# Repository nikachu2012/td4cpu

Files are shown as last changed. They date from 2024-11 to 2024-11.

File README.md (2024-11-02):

# TD4 CPU
書籍「CPUの創りかた」にあるTD4 CPUの回路を、ユニバーサル基板で作るのがめんどくさかったので基板にしたものです。
製作の際は書籍を購入することをお勧めします。

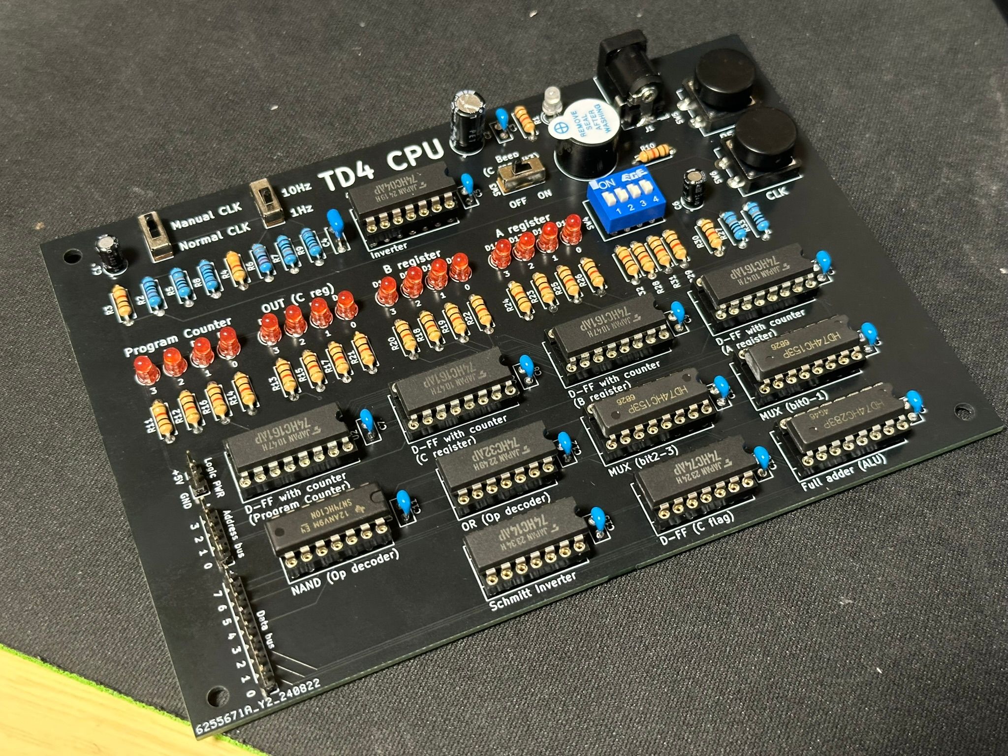
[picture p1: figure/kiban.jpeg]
kiban

*完成させた基板のサンプル*

## フォルダ解説
### `schematic`
回路図と基板のKiCadデータが入っています。バージョンは8.0です。
なんかのフットプリントをライブラリで入れてた気がしますがなくても読めるっぽいです。

### `schematic_pdf`
回路図のpdfファイルが入っています。

### `rom_emulator`
ArduinoなどのマイコンでROMを作るためのプログラムが入っています。  
Arduino UNO系と、Raspberry Pi Pico(MicroPython)があります。

#### Arduino UNO系
Arduino UNO R4 WiFiで動作確認しています。  
ポートレジスタの操作ではなく`digitalWrite`を使っているのでMinimaやR3でも動くと思います。

以下のように接続してください。

| Arduino側 | TD4 CPU側 |
| --- | --- |
| VIN | +5V |
| GND | GND |
| D11 | Address bus 3 |
| D10 | Address bus 2 |
| D9 | Address bus 1 |
| D8 | Address bus 0 |
| D7 | Data bus 7 |
| D6 | Data bus 6 |
| D5 | Data bus 5 |
| D4 | Data bus 4 |
| D3 | Data bus 3 |
| D2 | Data bus 2 |
| D1 | Data bus 1 |
| D0 | Data bus 0 |

#### Raspberry Pi Pico
Raspberry Pi Pico無印で動作確認済みです。
ファイル名を`main.py`に変更して送信すれば動作すると思います。

以下のように接続してください。

| Raspberry Pi Pico側 | TD4 CPU側 |
| --- | --- |
| 39 VSYS | +5V |
| 38 GND | GND |
| 4  GP2 | Address bus 3 |
| 5  GP3 | Address bus 2 |
| 6  GP4 | Address bus 1 |
| 7  GP5 | Address bus 0 |
| 9  GP6 | Data bus 7 |
| 10 GP7 | Data bus 6 |
| 11 GP8 | Data bus 5 |
| 12 GP9 | Data bus 4 |
| 13 GP10 | Data bus 3 |
| 14 GP11 | Data bus 2 |
| 15 GP12 | Data bus 1 |
| 16 GP13 | Data bus 0 |

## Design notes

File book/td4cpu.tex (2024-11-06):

\documentclass[xelatex,a5paper,ja=standard, openany]{bxjsbook}

\input{preamble.tex}

\title{}
\author{} 
\date{}

\begin{document}
\tableofcontents

\chapter{CPUの概要}

CPUの基板をご購入いただきありがとうございます。と説明書っぽいことを言ってみる。まあ書くこともないし、紙が無駄なのでこれぐらいにする。

\section{基板}

\begin{figure}[h]
    \centering
    
    \caption{完成した基板}
    \label{fig:kanseikiban}
\end{figure}

このCPUは、書籍「CPUの創りかた\footnote{\texttt{\url{https://book.mynavi.jp/ec/products/detail/id=22065} (ISBN4-8399-0986-5)}}」で製作するTD4 CPUの回路を、筆者が基板に起こしたものになる。\par
書籍ではユニバーサル基板上に配線していたが、そんなことしたくなかったので基板を作ることにした。基板設計など一切したことなかったので、専門家が見たら怒る点もあると思うが、気にしないでほしい。
部品を実装すれば動くと思うが、書籍も参照しながら作ることをおすすめする。\par

基板の設計はKiCad 8.0を利用した。無料のCADだが非常に使いやすかった。また、基板はJLCPCBに発注した。
\section{CPU}
CPUの概要を以下に示す。

\begin{itemize}
    \item 命令データ長 8bit
    \item アドレスバス長 4bit
    \item 2つの4bitレジスタ(A,B)
    \item 4bit 入出力 (IN, OUT)
    \item 4bit プログラムカウンタ
    \item ALUは全加算器のみ
\end{itemize}

命令フォーマットは、図\ref{fig:op_format}のように、上位4bitが命令コード、下位4bitがイミディエイトデータの計8bit構成となっている。
\begin{figure}[h]
    \centering
    
    \caption{命令フォーマット}
    \label{fig:op_format}
\end{figure}

\newpage
命令コードの一覧と意味、ニーモニックを表\ref{table:opcode_list}に示す。

\begin{table}[h]
    \centering
    \begin{tabular}{lll}
        ニーモニック                   & 命令コード                  & 意味                                       \\
        \hline
        \texttt{MOV A, {[}Im{]}} & \texttt{0011 {[}Im{]}} & A\textleftarrow Im                       \\
        \texttt{MOV B, {[}Im{]}} & \texttt{0111 {[}Im{]}} & B\textleftarrow Im                       \\
        \texttt{MOV A, B}        & \texttt{0001 0000}     & A\textleftarrow B                        \\
        \texttt{MOV B, A}        & \texttt{0100 0000}     & B\textleftarrow A                        \\
        \texttt{ADD A, {[}Im{]}} & \texttt{0000 {[}Im{]}} & A\textleftarrow A + Im                   \\
        \texttt{ADD B, {[}Im{]}} & \texttt{0101 {[}Im{]}} & B\textleftarrow B + Im                   \\
        \texttt{IN A}            & \texttt{0010 0000}     & A\textleftarrow IN                       \\
        \texttt{IN B}            & \texttt{0110 0000}     & B\textleftarrow IN                       \\
        \texttt{OUT {[}Im{]}}    & \texttt{1011 {[}Im{]}} & OUT\textleftarrow Im                     \\
        \texttt{OUT B}           & \texttt{1001 {[}Im{]}} & OUT\textleftarrow Im                     \\
        \texttt{JMP {[}Im{]}}    & \texttt{1111 {[}Im{]}} & PC\textleftarrow Im                      \\
        \texttt{JNC {[}Im{]} }   & \texttt{1110 {[}Im{]}} & if (C is not 1) then PC\textleftarrow Im
    \end{tabular}
    \caption{命令コードの一覧}
    \label{table:opcode_list}
\end{table}

\chapter{製作}
CPUの概要や回路を説明するのは書籍に任せるとして、この基板の製作について述べる。

\section{部品表}
基板以外に別途、別紙１に示した部品が必要となる。部品は必要個数のみ表記しているので、予備も含めて買うのをお勧めする。\par

部品については秋月電子通商\footnote{\url{https://akizukidenshi.com/catalog/default.aspx}}と樫木総業株式会社\footnote{\url{https://www.kashinoki.shop/}}ですべて購入できる。秋月電子通商で買える部品については秋葉原店の店頭ですべて購入できた(2024年8月現在)。\texttt{74HC14}だけバックヤードにあるためレジで店員に言わなければならないので注意。\par

秋葉原には秋月以外にもマルツや千石通商など、電子部品の店が多くある。この機会に秋葉原に出向いて色々なお店を見ながら選ぶと楽しいと思う。

\section{部品の実装}
はんだごて片手にひたすらはんだ付けする。表面実装部品は無いのではんだ付けの難易度は低いと思う。ただ量が多い。\par
暇だったのでアニメを見ながらはんだ付けをしていた。\par
このCPUの製作ではんだ付けを初めて行うという人は、はんだ付けの動画などを見て学ぶことをお勧めする。くれぐれも火傷には気を付けてほしい。

\subsection{注意点}
部品実装の注意点としては、電解コンデンサ(MLCCと書いていないもの)は極性\footnote{簡単に言えば部品のプラスマイナスの向きのこと。逆につなぐと爆発などの危険がある}がある。

\begin{figure}[ht]
    \centering
    \begin{minipage}[t]{0.45\linewidth}
        \centering
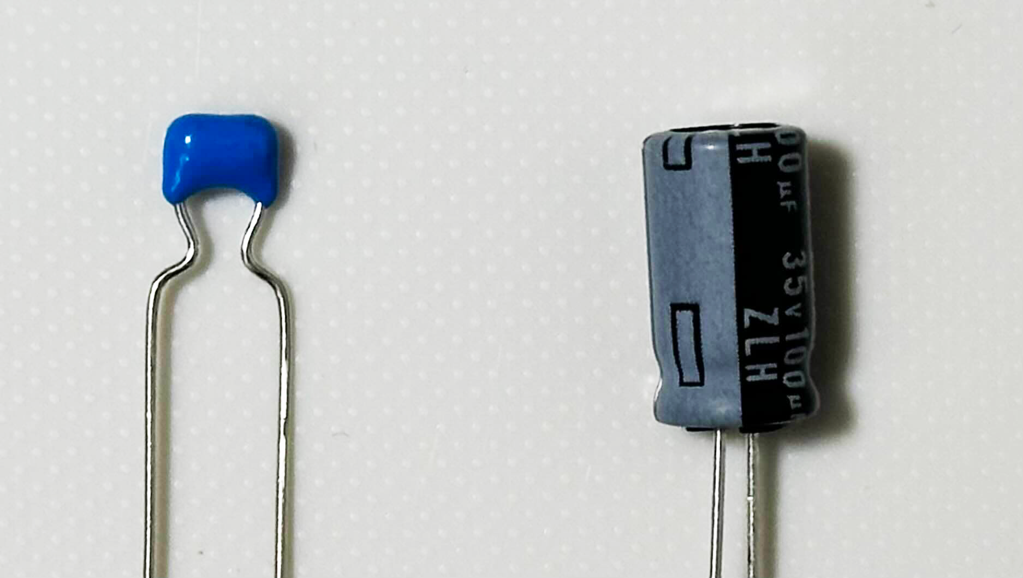
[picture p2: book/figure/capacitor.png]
        
        \caption{積層セラミックコンデンサ(左)と電解コンデンサ(右)}
        \label{fig:capacitor}
    \end{minipage}
    \begin{minipage}[t]{0.45\linewidth}
        \centering
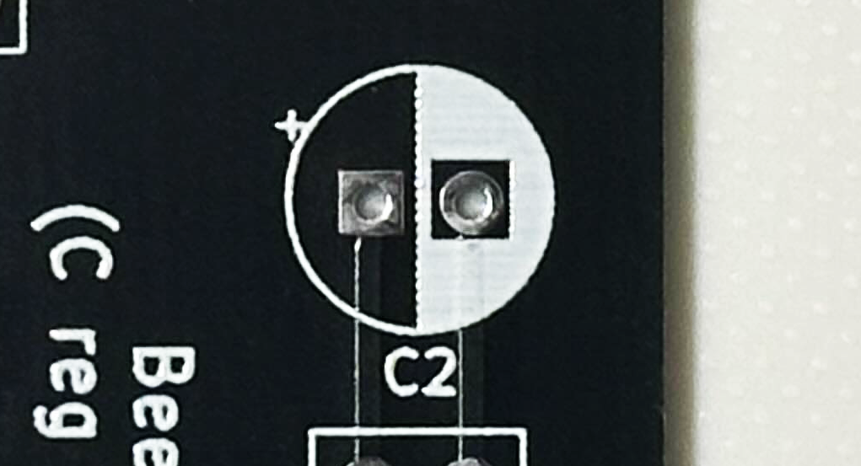
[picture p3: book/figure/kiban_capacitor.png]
        
        \caption{基板上の電解コンデンサの表記}
        \label{fig:capacitor_kiban}
    \end{minipage}
\end{figure}

電解コンデンサを見ると半分が白くなっていて、でかでかと-（マイナス）が書かれていると思う。これと基板上の白い部分の向きを合わせれば問題ない。また、積層セラミックコンデンサについては極性はない。\par

\hrulefill

\begin{figure}[h]
    \centering
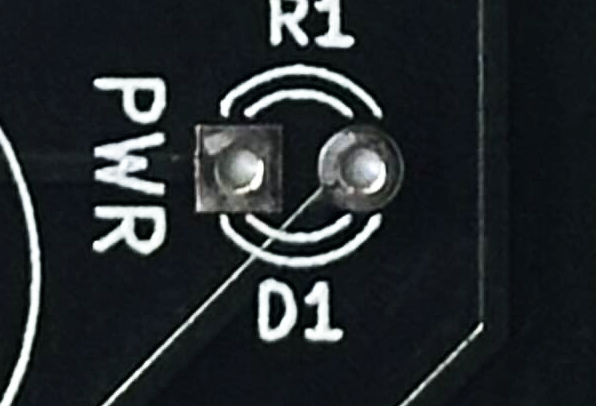
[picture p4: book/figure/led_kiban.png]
    
    \caption{基板上のLEDの表記}
    \label{fig:led_kiban}
\end{figure}

電源やレジスタの値の表示用にLED(発光ダイオード)を利用している。これも極性があるので注意してほしい。部品を刺す穴の周りの金属が四角いほう(図\ref{fig:led_kiban}では左側)がマイナス(LEDの足が短い方)になる。最悪こちらは逆につないでも光らないだけで回路に影響は無いはず。

ICは印刷されている切り欠きとICの切り欠きを合わせて差し込むようにする。逆だと正しく動かなかったり、ICを壊す可能性もある。というか絶対に壊す。ICソケットを使用する場合はICソケットにも切り欠きがあるので合わせるのが良い。

\begin{figure}[ht]
    \centering
    \begin{minipage}[t]{0.4\linewidth}
        \centering
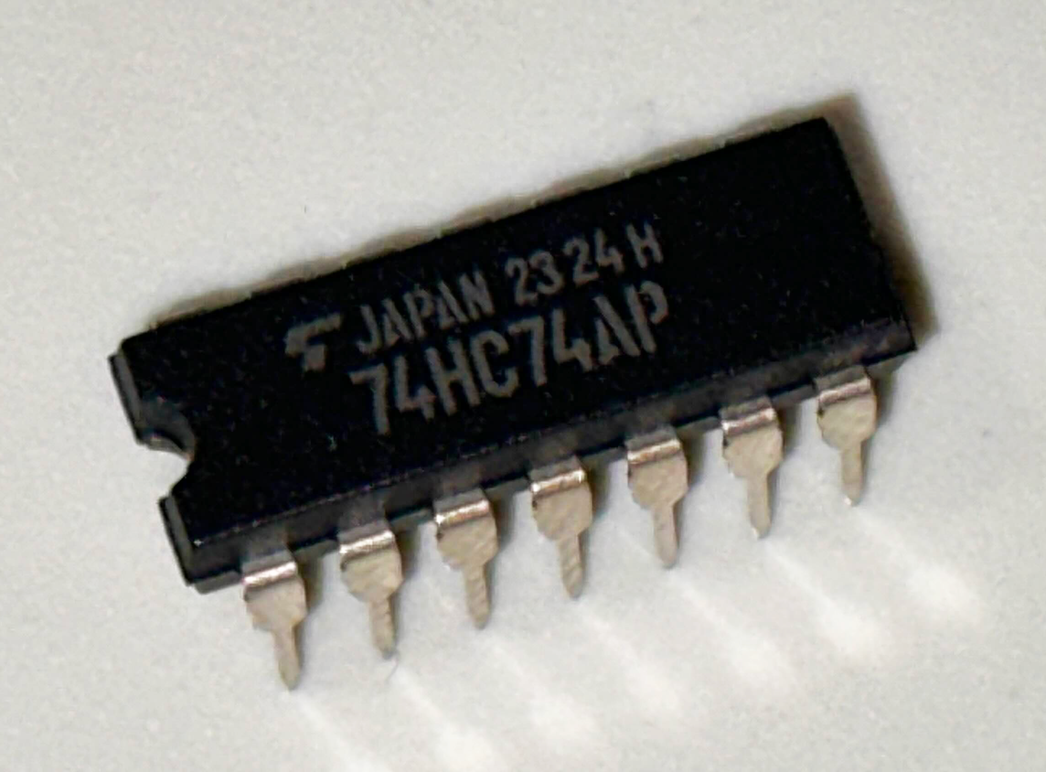
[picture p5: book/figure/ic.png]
        
        \caption{ICの外観}
        \label{fig:ic_overview}
    \end{minipage}
    \begin{minipage}[t]{0.45\linewidth}
        \centering
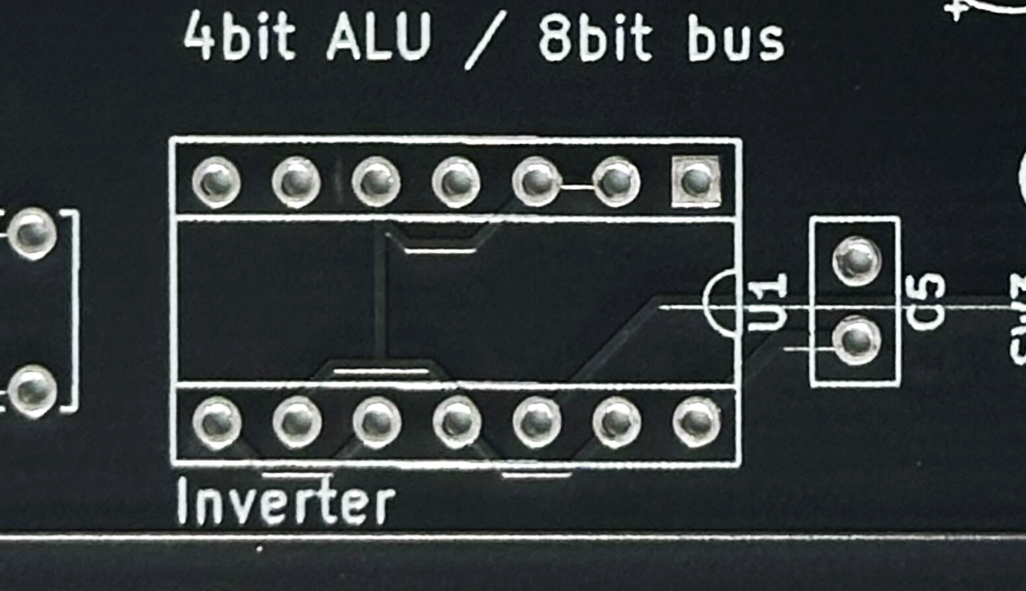
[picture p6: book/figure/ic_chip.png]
        
        \caption{基板上のICの印刷}
        \label{fig:ic_print}
    \end{minipage}
\end{figure}

\chapter{動作確認と使用}
はんだ付けが終わって完成してもTD4 CPUにはROMがないため、正しく動かない。そのためにまずはROMを用意する必要がある。

\section{ROM}
書籍ではROMは16個8PDIPスイッチを並べて製作していた。この方法はビジュアルとしては良いが結構部品代がかかるので断念した。
アドレスバスとデータバスを引き出しているので、ここに適当なROMを接続すれば良いが、筆者はArduinoでROMを作ることにした。

\begin{figure}[h]
    \centering
    
    \caption{Arduinoで作ったROMで動くTD4 CPU}
    \label{fig:td4withROM}
\end{figure}

\newpage

プログラムは以下の通り。

\lstinputlisting[language=c++]{td4_rom_arduino_new.ino}

Arduino UNO R4 WiFiで動作確認しているが、他でも動くと思う。あとはArduino側のD0-D7ピンをデータバスの0-7に、D8-D11をアドレスバスの0-3にそれぞれ接続し、+5VとVinを接続し、GND同士を接続してどちらかに電源を入れればプログラムが実行される。\par

\newpage

またPWRピンがあるがこれは入出力どちらでも使えるので、Arduino側から供給しても\footnote{Arduino側から供給する場合、電流制限に注意}、CPU側から供給しても良い。

\section{アセンブラー}
書籍ではアセンブル\footnote{人間に読みやすいように書かれたニーモニックを機械語に変換する処理}はハンドアセンブルのみが書かれていたが、めんどくさかったのでアセンブラーを作った。Linux上で動かすことを想定しているので、Windowsを使っている場合WSL上で行うことをお勧めする。

ビルドには\texttt{gcc, make, git, flex, bison}が必要なのでインストールする。Ubuntuを利用している場合は以下の通りになる。
\begin{lstlisting}
$ sudo apt update
$ sudo apt upgrade
$ sudo apt install gcc make git flex bison libbison-dev
\end{lstlisting}

ビルドは以下のコマンドで行う。
\begin{lstlisting}
$ cd ~
$ git clone https://github.com/nikachu2012/td4asm
$ cd td4asm
$ make all
\end{lstlisting}

test.asmというファイルををtd4asmと同じ場所に作り、中身を以下のようにする。
\begin{lstlisting}[caption=LEDちかちかさせるプログラム \texttt{test.asm}]
main: out 0b0011
      out 0b0110
      out 0b1100
      out 0b1000
      out 0b1000
      out 0b1100
      out 0b0110
      out 0b0011
      out 0b0001
      jmp main
\end{lstlisting}

以下のコマンドを実行するとtest.txtが作られる。
\begin{lstlisting}
$ ./td4asm -i test.asm -o test.txt -c
\end{lstlisting}

test.txtは以下のようになる。
\begin{lstlisting}
{0xb3, 0xb6, 0xbc, 0xb8, 0xb8, 0xbc, 0xb6, 0xb3, 0xb1, 0xf0, 0x00, 0x00, 0x00, 0x00, 0x00, 0x00}
\end{lstlisting}

このように、C言語の配列形式で機械語が出力される。

\chapter{最後に}

この本のPDFファイル、回路図などは以下のURLに用意した。

\centerline{\url{https://github.com/nikachu2012/td4cpu}}

また、すべての質問に答えられるかわからないが、このCPUの基板やアセンブラーについてわからない点などがあれば、奥付に記載のメールアドレスまで連絡していただければできるだけ質問に答える。

\vspace*{\fill}

\begin{tabular*}{\textwidth}{l}
    \noindent
    \textbf{\sffamily\Large 4bit CPU 製作基板\;説明書\normalsize}\vspace{3mm} \\
    \hline
    \begin{tabular}{@{}rrrl}
        2024年 & 11月 & 1日 & 初版第1刷発行\;\;(沼津高専\;第59回高専祭) \\
        % 2029年 & 1月 & 1日 & 初版第2刷発行\;\;(沼津高専\;第60回高専祭)
    \end{tabular} \\
    \\
    \begin{tabular}{@{}ll}
        \textbf{著者}  & \texttt{@nikachu2012} (荻野\;壮)                          \\
        \textbf{発行者} & \begin{tabular}{@{}l@{}}
                           \texttt{@nikachu2012} (荻野\;壮)  \\
                           \texttt{work@nikachu.net}
                       \end{tabular}               \\
        \textbf{発行所} & 沼津高専\;情報工学同好会(非公認)                          \\
        \textbf{印刷者} & 自分                                 \\
    \end{tabular} \\
    \hline
    Printed in Japan(多分)
\end{tabular*}

\end{document}

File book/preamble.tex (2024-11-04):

% 各種パッケージ
\usepackage{graphicx} % figure環境
\usepackage{titlesec}
\usepackage{hyperref}

\usepackage{noto}
\usepackage[T1]{fontenc} % 欧文フォント変えるときのおまじない

\usepackage{listings}
\renewcommand{\lstlistingname}{ソースコード}

\lstset{
    basicstyle={\ttfamily\gtfamily\scriptsize},
    identifierstyle={},
    commentstyle={},
    keywordstyle={\bfseries},
    ndkeywordstyle={},
    stringstyle={\ttfamily},
    frame={tb},
    breaklines=true,
    columns=[l]{fullflexible},
    numbers=left,
    numberstyle={\ttfamily\tiny},
    stepnumber=1,
    tabsize=4,
    keywordstyle={},     %キーワード(int, ifなど)の書体指定
    commentstyle={},  %注釈の書体
    stringstyle={},        %文字列
    showstringspaces=false,  %文字列中の半角スペースを表示させない
    keepspaces=true,
}

\pagestyle{headings}

% chapter
\titleformat{\chapter}[block]
{\bfseries\gtfamily\sffamily\Huge}
{\Large 第\thechapter 章\\\Huge}{0pt}
{}
[\titlerule]

\titlespacing*{\chapter}{0pt}{0em}{1.5em}[0pt] % 余白指定

% section
\titleformat{\section}[block]
{\bfseries\gtfamily\sffamily\Large}
{\thesection}{10pt}
{}
[\titlerule]

% subsection
\titleformat{\subsection}[block]
{\bfseries\gtfamily\sffamily\large}
{\thesubsection}{10pt}
{}
[\titlerule]

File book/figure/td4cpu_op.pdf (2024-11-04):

0 | 0 | 1 | 1 | 1 | 1 | 1 | 1
MSB | 7 | 6 | 5 | 4 | 3 | 2 | 1 | 0 | LSB
命令コード | イミディエイトデータ

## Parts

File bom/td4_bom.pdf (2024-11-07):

別紙１ 部品表 | 価格は2024年11月時点の価格
リファレンス番号 | 部品種類 | 販売ページ | メモ | 必要個数 参考単価 価格
BZ1 | Beep Buzzer | https://akizukidenshi.com/catalog/g/g109800/ | 12mmの電子ブザー
| | | (圧電スピーカーではなく、発振回路を内蔵しているやつ） | 1 | 70 | 70
C1,C6 | 10μF 16V | https://akizukidenshi.com/catalog/g/g110590/ | | 2 | 10 | 20
C2 | 100μF 16V | https://akizukidenshi.com/catalog/g/g102724/ | 大元の一番でかいコンデンサ | 1 | 15 | 15
C3,C5,C7-C17 | 0.1μF MLCC | https://akizukidenshi.com/catalog/g/g113582/ | 10個入り | 13 | 100 | 100
C4 | 10μF 16V MLCC | https://akizukidenshi.com/catalog/g/g102184/ | 10個入り | 1 | 200 | 200
D1-D17 | LED | https://akizukidenshi.com/catalog/g/g111577/ | 3mmのやつ
| | | 筆者は秋葉原マルツの処分セールでめっちゃ安いやつにした | 17 | | 100
J1 | Jack-DC | https://akizukidenshi.com/catalog/g/g109408/ | 内径2.1 外径5.5のやつ | 1 | 30 | 1
J2,J3,J4 | Logic, Address, Data | https://akizukidenshi.com/catalog/g/g100167/ | ピンヘッダ全部で14ピン分 | 3 | 35 | 35
R1,R3,R10-R26,R28-R32 | 1k | https://akizukidenshi.com/catalog/g/g125102/ | 100個入り 普通の抵抗 | 24 | 100 | 100
R2 | 10k | https://akizukidenshi.com/catalog/g/g125103/ | 100個入り 普通の抵抗 | 1 | 100 | 100
R4 | 3.3k | https://akizukidenshi.com/catalog/g/g125332/ | 100個入り 普通の抵抗 | 1 | 140 | 140
R5,R7,R27,R33 | 100k | https://akizukidenshi.com/catalog/g/g125104/ | 100個入り 普通の抵抗 | 4 | 130 | 130
R6 | 33k | https://akizukidenshi.com/catalog/g/g125333/ | 100個入り 普通の抵抗 | 1 | 150 | 150
R8,R9 | 100 | https://akizukidenshi.com/catalog/g/g125101/ | 100個入り 普通の抵抗 | 2 | 140 | 140
SW1,SW2,SW3 | SW_SPDT | https://akizukidenshi.com/catalog/g/g115707/ | 1回路2接点スライドスイッチ
| | | (クロック種別、周波数、ビープ音切り替え） | 3 | 20 | 60
SW4 | DIP | https://akizukidenshi.com/catalog/g/g100586/ | 4P DIPスイッチ (Cレジスタ入力用) | 1 | 80 | 80
SW5, SW6 | RESET, Manual CLK | https://akizukidenshi.com/catalog/g/g109826/ | 12mm角のタクトスイッチ (リセット、マニュアルクロック用) | 2 | 30 | 60
U1 | 74HC04 | https://akizukidenshi.com/catalog/g/g114058/ | インバータ DIP14P (ビープ音の電流を稼ぐため) | 1 | 30 | 30
U2,U3,U4,U5 | 74HC161 | https://www.kashinoki.shop/?pid=122479142 | 4bitカウンタ/レジスタ DIP16P
| | | (レジスタ、プログラムカウンタ) | 4 | 99 | 396
U6 | 74HC10 | https://www.kashinoki.shop/?pid=122479082 | 3入力3回路NAND DIP14P | 1 | 55 | 55
U7 | 74HC14 | https://akizukidenshi.com/catalog/g/g110923/ | シュミットトリガインバータ DIP14P | 1 | 40 | 40
U8 | 74HC32 | https://www.kashinoki.shop/?pid=122479093 | 4回路OR DIP14P | 1 | 28 | 28
U9 | 74HC74 | https://akizukidenshi.com/catalog/g/g110879/ | 2回路Dフリップフロップ DIP14P (Carry Flag) | 1 | 25 | 25
U10,U12 | 74HC153 | https://www.kashinoki.shop/?pid=122479134 | 4chマルチプレクサ DIP16P | 2 | 59 | 118
U11 | 74HC283 | https://www.kashinoki.shop/?pid=122479187 | 4bit全加算器 DIP16P (ALU) | 1 | 187 | 187
| | https://akizukidenshi.com/catalog/g/g100029/ | ICソケット 16P | 7 | 40 | 280
| | https://akizukidenshi.com/catalog/g/g100028/ | ICソケット 14P | 5 | 30 | 150
| | https://akizukidenshi.com/catalog/g/g111996/ | スイッチングACアダプタ 5V2A
| | | (内径2.1 外径5.5 センタープラス) | 1 | 770 | 770
@nikachu2012 | この部品表は以下のURLにもあります。 https://github.com/nikachu2012/td4cpu/blob/main/bom/td4_bom.csv

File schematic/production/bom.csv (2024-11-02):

Designator | Footprint | Quantity | Value | LCSC Part #
BZ1 | Buzzer_12x9.5RM7.6 | 1 | Beep Buzzer
C1, C6 | CP_Radial_D4.0mm_P1.50mm | 2 | 10μF 16V
C10, C11, C12, C13, C14, C15, C16, C17, C3, C5, C7, C8, C9 | C_Disc_D5.0mm_W2.5mm_P2.50mm | 13 | 0.1μF
C2 | CP_Radial_D6.3mm_P2.50mm | 1 | 100μF 16V
C4 | C_Disc_D6.0mm_W2.5mm_P5.00mm | 1 | 10μF 16V MLCC
D1, D10, D11, D12, D13, D14, D15, D16, D17, D2, D3, D4, D5, D6, D7, D8, D9 | LED_D3.0mm | 17 | LED
J1 | BarrelJack_GCT_DCJ200-10-A_Horizontal | 1 | Jack-DC
J2 | PinHeader_1x02_P2.54mm_Vertical | 1 | Power
J3 | PinHeader_1x04_P2.54mm_Vertical | 1 | ADDRESS
J4 | PinHeader_1x08_P2.54mm_Vertical | 1 | DATA
R1, R10, R11, R12, R13, R14, R15, R16, R17, R18, R19, R20, R21, R22, R23, R24, R25, R26, R28, R29, R3, R30, R31, R32 | R_Axial_DIN0207_L6.3mm_D2.5mm_P7.62mm_Horizontal | 24 | 1k
R2 | R_Axial_DIN0207_L6.3mm_D2.5mm_P7.62mm_Horizontal | 1 | 10k
R27, R33, R5, R7 | R_Axial_DIN0207_L6.3mm_D2.5mm_P7.62mm_Horizontal | 4 | 100k
R4 | R_Axial_DIN0207_L6.3mm_D2.5mm_P7.62mm_Horizontal | 1 | 3.3k
R6 | R_Axial_DIN0207_L6.3mm_D2.5mm_P7.62mm_Horizontal | 1 | 33k
R8, R9 | R_Axial_DIN0207_L6.3mm_D2.5mm_P7.62mm_Horizontal | 2 | 100
SW1, SW2 | SS12D00G3 | 2 | SW_SPDT
SW3 | SS12D00G3 | 1 | Beep Toggle
SW4 | SW_DIP_SPSTx04_Slide_9.78x12.34mm_W7.62mm_P2.54mm | 1 | DIP
SW5 | SW_PUSH-12mm_Wuerth-430476085716 | 1 | Reset SW
SW6 | SW_PUSH-12mm_Wuerth-430476085716 | 1 | Manual CLK
U1 | DIP-14_W7.62mm_Socket | 1 | 74HC04
U10, U12 | DIP-16_W7.62mm_Socket | 2 | 74HC153
U11 | DIP-16_W7.62mm_Socket | 1 | 74HC283
U2, U3, U4, U5 | DIP-16_W7.62mm_Socket | 4 | 74HC161
U6 | DIP-14_W7.62mm_Socket | 1 | 74HC10
U7 | DIP-14_W7.62mm_Socket | 1 | 74HC14
U8 | DIP-14_W7.62mm_Socket | 1 | 74HC32
U9 | DIP-14_W7.62mm_Socket | 1 | 74HC74

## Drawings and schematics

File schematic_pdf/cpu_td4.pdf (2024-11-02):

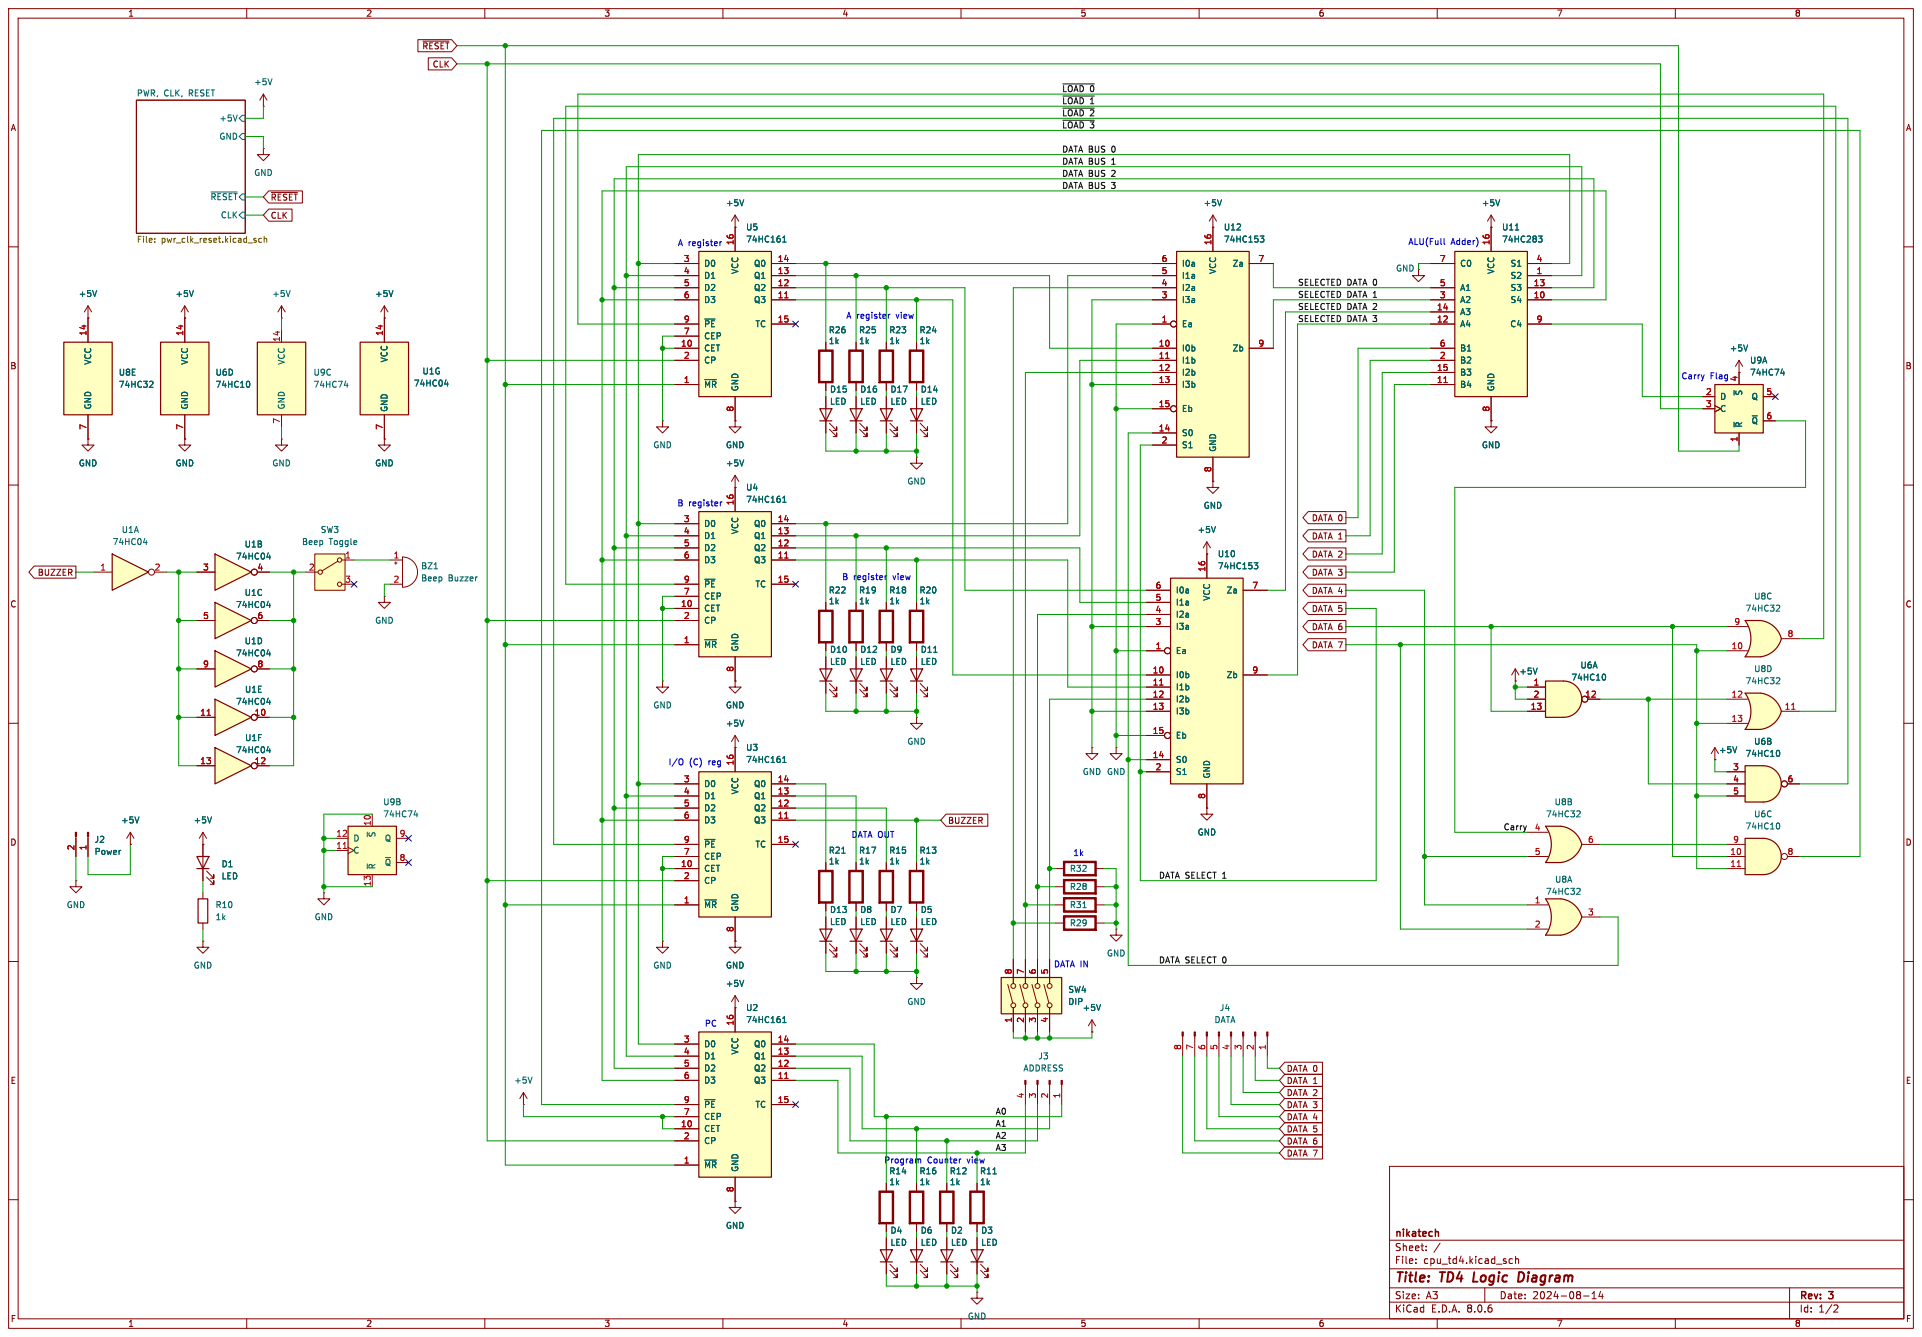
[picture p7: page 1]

~{RESET} PWR, CLK, RESET

ALU(Full Adder) DATA OUT B register
1k A register

DATA 5 DATA 0 DATA 3 DATA 7 DATA 2 DATA 6

DATA 3 DATA 5 DATA 0 DATA 4 DATA 1 BUZZER

Id: 1/2 Title: TD4 Logic Diagram

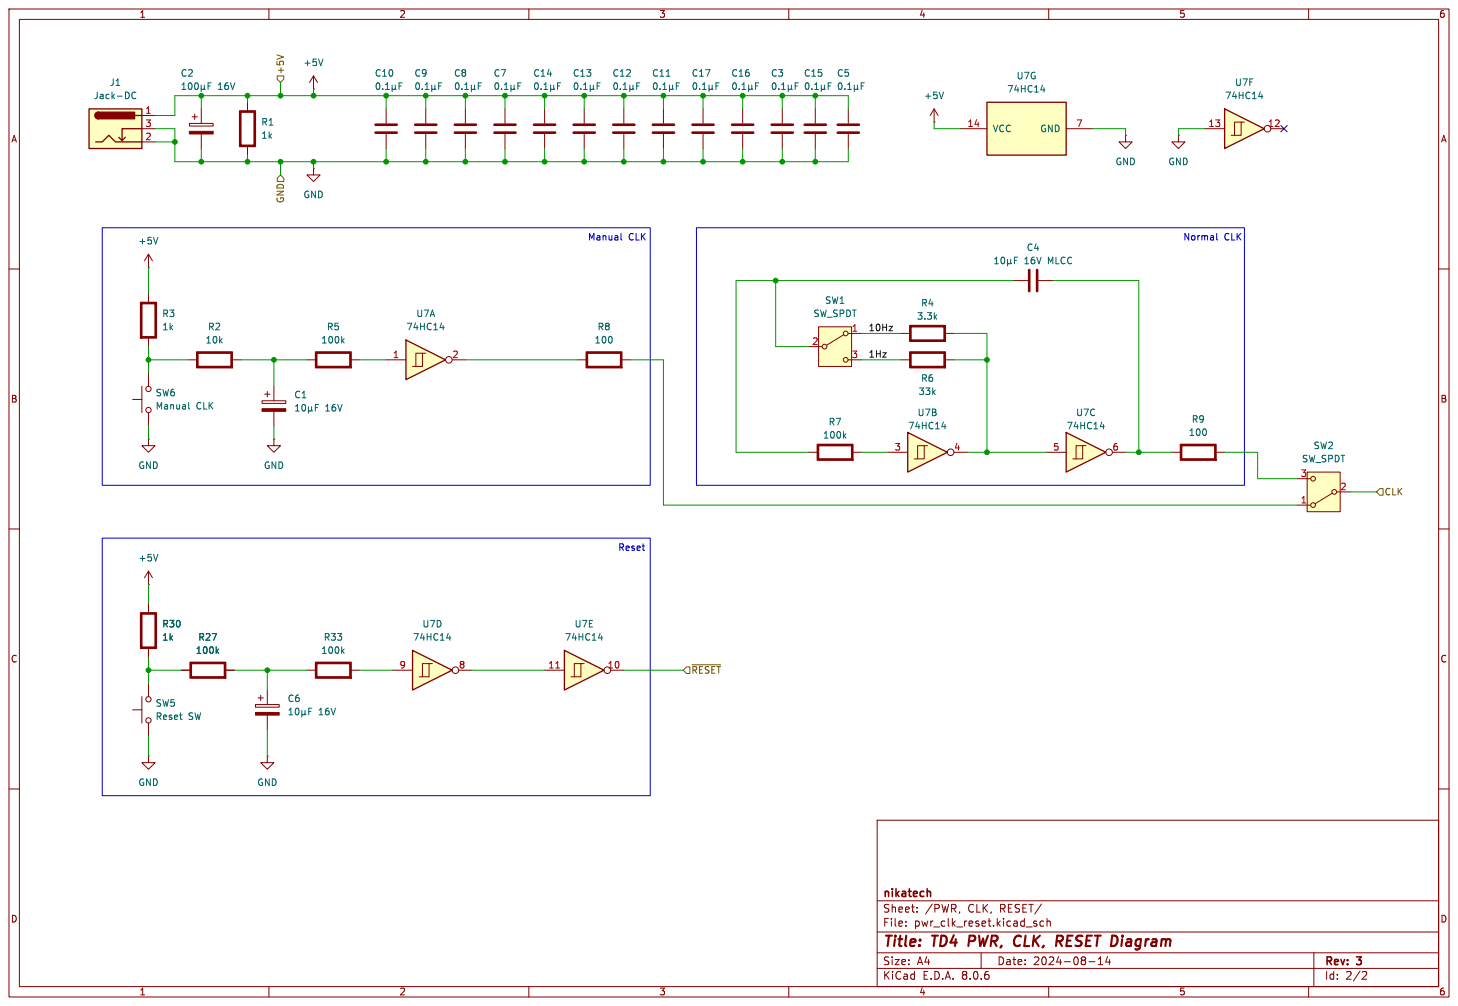
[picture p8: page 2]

Id: 2/2 Title: TD4 PWR, CLK, RESET Diagram

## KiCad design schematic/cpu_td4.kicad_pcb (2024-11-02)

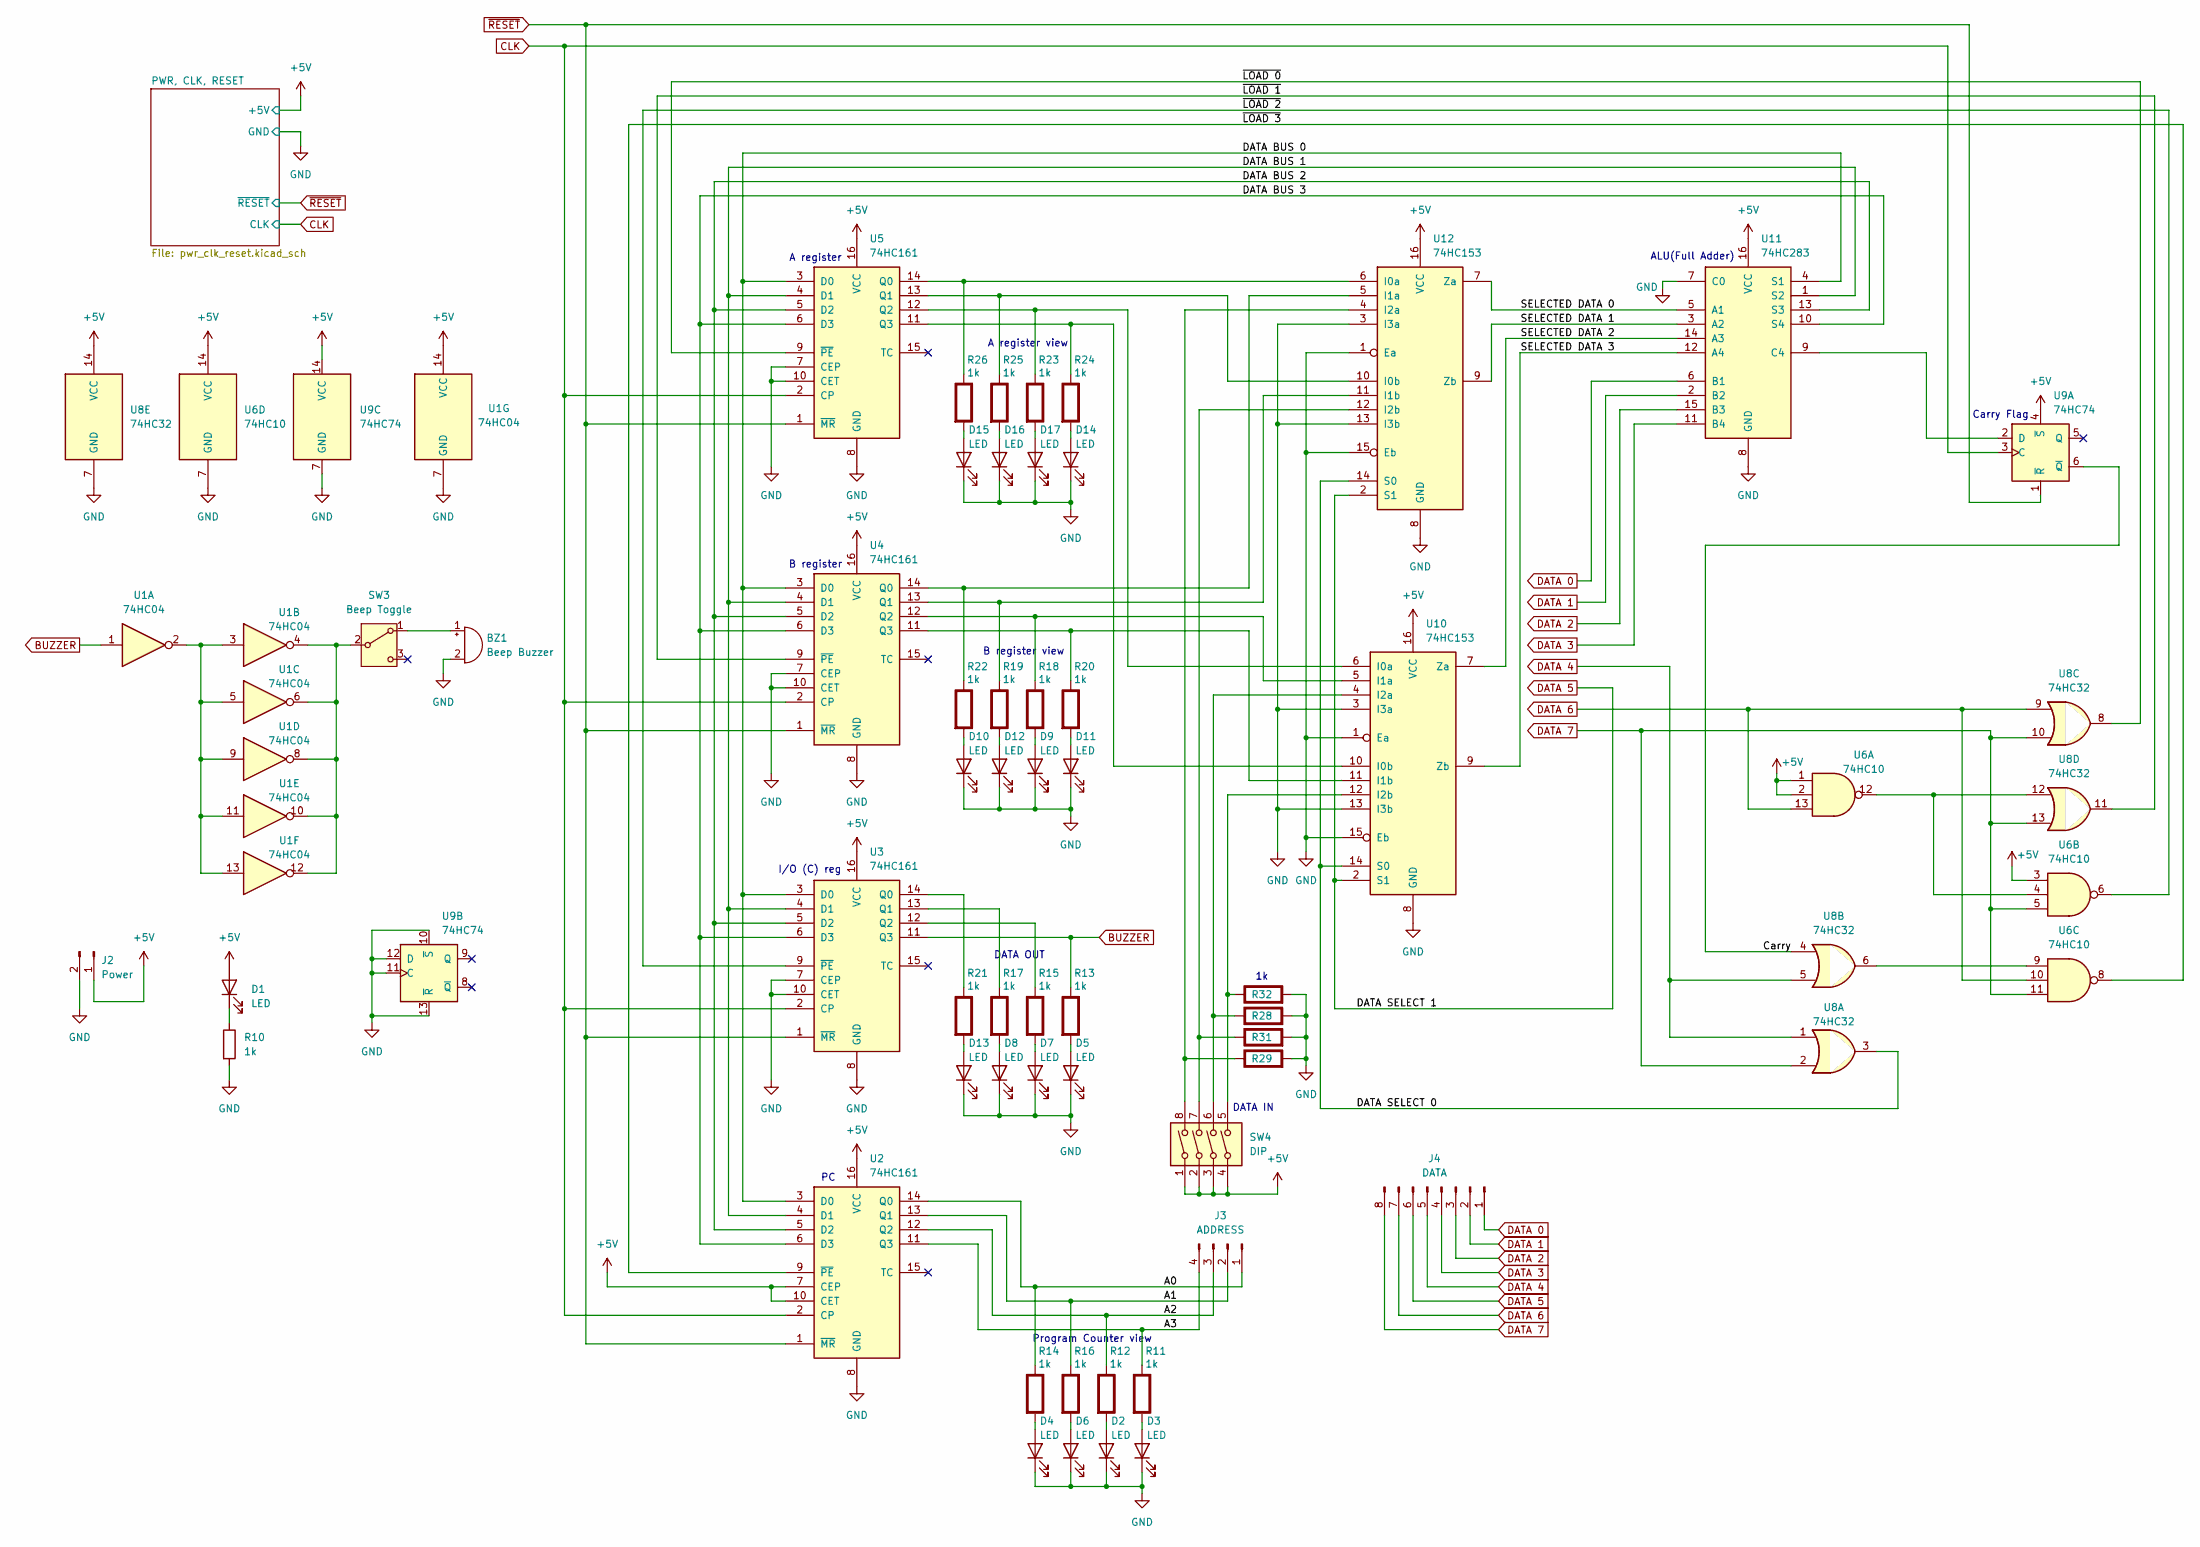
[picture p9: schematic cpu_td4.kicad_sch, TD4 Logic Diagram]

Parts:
BZ1: Beep Buzzer; Buzzer_12x9.5RM7.6
D1, D2, D3, D4, D5, D6, D7, D8, D9, D10, D11, D12, D13, D14, D15, D16, D17: LED; LED_D3.0mm
J2: Power; PinHeader_1x02_P2.54mm_Vertical
J3: ADDRESS; PinHeader_1x04_P2.54mm_Vertical
J4: DATA; PinHeader_1x08_P2.54mm_Vertical
R10: 1k; R_Axial_DIN0207_L6.3mm_D2.5mm_P7.62mm_Horizontal
R11, R12, R13, R14, R15, R16, R17, R18, R19, R20, R21, R22, R23, R24, R25, R26, R28, R29, R31, R32: 1k; R_Axial_DIN0207_L6.3mm_D2.5mm_P7.62mm_Horizontal; Rating W
SW3: Beep Toggle; SS12D00G3
SW4: DIP; SW_DIP_SPSTx04_Slide_9.78x12.34mm_W7.62mm_P2.54mm
U1: 74HC04; DIP-14_W7.62mm_Socket
U2, U3, U4, U5: 74HC161; DIP-16_W7.62mm_Socket
U6: 74HC10; DIP-14_W7.62mm_Socket
U8: 74HC32; DIP-14_W7.62mm_Socket
U9: 74HC74; DIP-14_W7.62mm_Socket
U10, U12: 74HC153; DIP-16_W7.62mm_Socket
U11: 74HC283; DIP-16_W7.62mm_Socket

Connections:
+5V: D1.2 (A), J2.1, SW4.1, SW4.2, SW4.3, SW4.4, U1.14 (VCC), U2.7 (CEP), U2.10 (CET), U2.16 (VCC), U3.16 (VCC), U4.16 (VCC), U5.16 (VCC), U6.1, U6.2, U6.3, U6.14 (VCC), U8.14 (VCC), U9.4 (~S), U9.14 (VCC), U10.16 (VCC), U11.16 (VCC), U12.16 (VCC); also elsewhere on the board
/A0: J3.1, R14.1 (+), U2.14 (Q0)
/A1: J3.2, R16.1 (+), U2.13 (Q1)
/A2: J3.3, R12.1 (+), U2.12 (Q2)
/A3: J3.4, R11.1 (+), U2.11 (Q3)
/Carry: U8.4, U9.6 (~Q)
/DATA BUS 0: U2.3 (D0), U3.3 (D0), U4.3 (D0), U5.3 (D0), U11.4 (S1)
/DATA BUS 1: U2.4 (D1), U3.4 (D1), U4.4 (D1), U5.4 (D1), U11.1 (S2)
/DATA BUS 2: U2.5 (D2), U3.5 (D2), U4.5 (D2), U5.5 (D2), U11.13 (S3)
/DATA BUS 3: U2.6 (D3), U3.6 (D3), U4.6 (D3), U5.6 (D3), U11.10 (S4)
/DATA SELECT 0: U8.3, U10.14 (S0), U12.14 (S0)
/SELECTED DATA 0: U11.5 (A1), U12.7 (Za)
/SELECTED DATA 1: U11.3 (A2), U12.9 (Zb)
/SELECTED DATA 2: U10.7 (Za), U11.14 (A3)
/SELECTED DATA 3: U10.9 (Zb), U11.12 (A4)
/~LOAD 0: U5.9 (~PE), U8.8
/~LOAD 1: U4.9 (~PE), U8.11
/~LOAD 2: U3.9 (~PE), U6.6
/~LOAD 3: U2.9 (~PE), U6.8
BUZZER: R13.1 (+), U1.1, U3.11 (Q3)
CLK: U2.2 (CP), U3.2 (CP), U4.2 (CP), U5.2 (CP), U9.3 (C); also elsewhere on the board
DATA 0: J4.1, U11.6 (B1)
DATA 1: J4.2, U11.2 (B2)
DATA 2: J4.3, U11.15 (B3)
DATA 3: J4.4, U11.11 (B4)
DATA 4: J4.5, U8.1, U8.5
DATA 5: J4.6, U10.2 (S1), U12.2 (S1)
DATA 6: J4.7, U6.10, U6.13, U8.9
DATA 7: J4.8, U6.5, U6.11, U8.2, U8.10, U8.13
GND: BZ1.2 (-), D2.1 (K), D3.1 (K), D4.1 (K), D5.1 (K), D6.1 (K), D7.1 (K), D8.1 (K), D9.1 (K), D10.1 (K), D11.1 (K), D12.1 (K), D13.1 (K), D14.1 (K), D15.1 (K), D16.1 (K), D17.1 (K), J2.2, R10.2, R28.2 (-), R29.2 (-), R31.2 (-), R32.2 (-), U1.7 (GND), U2.8 (GND), U3.7 (CEP), U3.8 (GND), U3.10 (CET), U4.7 (CEP), U4.8 (GND), U4.10 (CET), U5.7 (CEP), U5.8 (GND), U5.10 (CET), U6.7 (GND), U8.7 (GND), U9.7 (GND), U9.10 (~S), U9.11 (C), U9.12 (D), U9.13 (~R), U10.1 (Ea), U10.3 (I3a), U10.8 (GND), U10.13 (I3b), U10.15 (Eb), U11.7 (C0), U11.8 (GND), U12.1 (Ea), U12.3 (I3a), U12.8 (GND), U12.13 (I3b), U12.15 (Eb); also elsewhere on the board
unnamed: BZ1.1 (+), SW3.1 (A)
unnamed: D1.1 (K), R10.1
unnamed: D2.2 (A), R12.2 (-)
unnamed: D3.2 (A), R11.2 (-)
unnamed: D4.2 (A), R14.2 (-)
unnamed: D5.2 (A), R13.2 (-)
unnamed: D6.2 (A), R16.2 (-)
unnamed: D7.2 (A), R15.2 (-)
unnamed: D8.2 (A), R17.2 (-)
unnamed: D9.2 (A), R18.2 (-)
unnamed: D10.2 (A), R22.2 (-)
unnamed: D11.2 (A), R20.2 (-)
unnamed: D12.2 (A), R19.2 (-)
unnamed: D13.2 (A), R21.2 (-)
unnamed: D14.2 (A), R24.2 (-)
unnamed: D15.2 (A), R26.2 (-)
unnamed: D16.2 (A), R25.2 (-)
unnamed: D17.2 (A), R23.2 (-)
unnamed: R15.1 (+), U3.12 (Q2)
unnamed: R17.1 (+), U3.13 (Q1)
unnamed: R18.1 (+), U4.12 (Q2), U10.5 (I1a)
unnamed: R19.1 (+), U4.13 (Q1), U12.11 (I1b)
unnamed: R20.1 (+), U4.11 (Q3), U10.11 (I1b)
unnamed: R21.1 (+), U3.14 (Q0)
unnamed: R22.1 (+), U4.14 (Q0), U12.5 (I1a)
unnamed: R23.1 (+), U5.12 (Q2), U10.6 (I0a)
unnamed: R24.1 (+), U5.11 (Q3), U10.10 (I0b)
unnamed: R25.1 (+), U5.13 (Q1), U12.10 (I0b)
unnamed: R26.1 (+), U5.14 (Q0), U12.6 (I0a)
unnamed: R28.1 (+), SW4.6, U10.4 (I2a)
unnamed: R29.1 (+), SW4.8, U12.4 (I2a)
unnamed: R31.1 (+), SW4.7, U12.12 (I2b)
unnamed: R32.1 (+), SW4.5, U10.12 (I2b)
unnamed: SW3.2 (B), U1.4, U1.6, U1.8, U1.10, U1.12
unnamed: U1.2, U1.3, U1.5, U1.9, U1.11, U1.13
unnamed: U6.9, U8.6
unnamed: U6.4, U6.12, U8.12
unnamed: U9.2 (D), U11.9 (C4)
~RESET: U2.1 (~MR), U3.1 (~MR), U4.1 (~MR), U5.1 (~MR), U9.1 (~R); also elsewhere on the board

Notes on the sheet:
ALU(Full Adder)
A register view
DATA OUT
B register
I/O (C) reg
Program Counter view
B register view
A register
DATA IN
Carry Flag

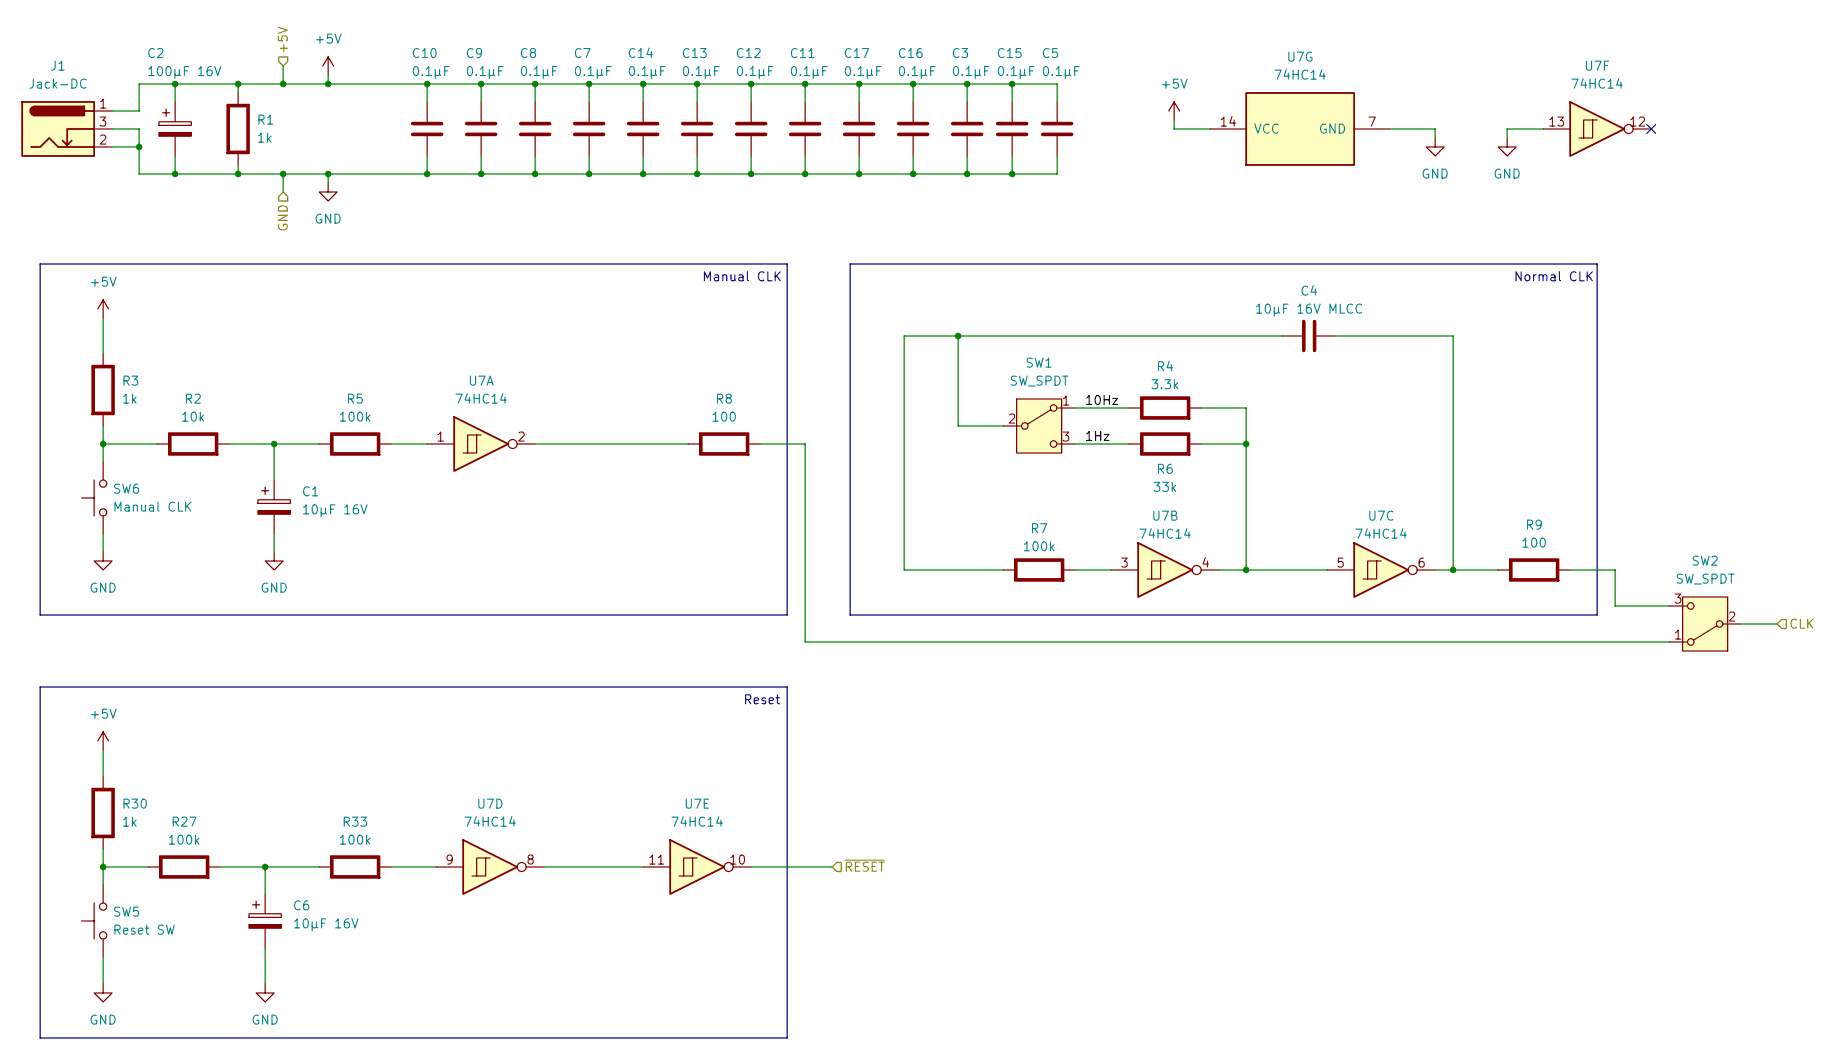
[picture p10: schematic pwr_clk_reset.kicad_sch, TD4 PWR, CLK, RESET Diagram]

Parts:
C1, C6: 10μF 16V; CP_Radial_D4.0mm_P1.50mm
C2: 100μF 16V; CP_Radial_D6.3mm_P2.50mm
C3, C5, C7, C8, C9, C10, C11, C12, C13, C14, C15, C16, C17: 0.1μF; C_Disc_D5.0mm_W2.5mm_P2.50mm
C4: 10μF 16V MLCC; C_Disc_D6.0mm_W2.5mm_P5.00mm
J1: Jack-DC; BarrelJack_GCT_DCJ200-10-A_Horizontal
R1, R3, R30: 1k; R_Axial_DIN0207_L6.3mm_D2.5mm_P7.62mm_Horizontal; Rating W
R2: 10k; R_Axial_DIN0207_L6.3mm_D2.5mm_P7.62mm_Horizontal; Rating W
R4: 3.3k; R_Axial_DIN0207_L6.3mm_D2.5mm_P7.62mm_Horizontal; Rating W
R5, R7, R27, R33: 100k; R_Axial_DIN0207_L6.3mm_D2.5mm_P7.62mm_Horizontal; Rating W
R6: 33k; R_Axial_DIN0207_L6.3mm_D2.5mm_P7.62mm_Horizontal; Rating W
R8, R9: 100; R_Axial_DIN0207_L6.3mm_D2.5mm_P7.62mm_Horizontal; Rating W
SW1, SW2: SW_SPDT; SS12D00G3
SW5: Reset SW; SW_PUSH-12mm_Wuerth-430476085716
SW6: Manual CLK; SW_PUSH-12mm_Wuerth-430476085716
U7: 74HC14; DIP-14_W7.62mm_Socket

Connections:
+5V: C2.1, C3.1, C5.1, C7.1, C8.1, C9.1, C10.1, C11.1, C12.1, C13.1, C14.1, C15.1, C16.1, C17.1, J1.1, R1.1 (+), R3.1 (+), R30.1 (+), U7.14 (VCC); also elsewhere on the board
/PWR, CLK, RESET/1Hz: R6.1 (+), SW1.3 (C)
/PWR, CLK, RESET/10Hz: R4.1 (+), SW1.1 (A)
CLK: SW2.2 (B); also elsewhere on the board
GND: C1.2, C2.2, C3.2, C5.2, C6.2, C7.2, C8.2, C9.2, C10.2, C11.2, C12.2, C13.2, C14.2, C15.2, C16.2, C17.2, J1.2, J1.3, R1.2 (-), SW5.1, SW6.1, U7.7 (GND), U7.13; also elsewhere on the board
unnamed: R2.1 (+), R3.2 (-), SW6.2
unnamed: C1.1, R2.2 (-), R5.1 (+)
unnamed: R4.2 (-), R6.2 (-), U7.4, U7.5
unnamed: R5.2 (-), U7.1
unnamed: C4.1, R7.1 (+), SW1.2 (B)
unnamed: R7.2 (-), U7.3
unnamed: R8.1 (+), U7.2
unnamed: R8.2 (-), SW2.1 (A)
unnamed: C4.2, R9.1 (+), U7.6
unnamed: R9.2 (-), SW2.3 (C)
unnamed: R27.1 (+), R30.2 (-), SW5.2
unnamed: C6.1, R27.2 (-), R33.1 (+)
unnamed: R33.2 (-), U7.9
unnamed: U7.8, U7.11
~RESET: U7.10; also elsewhere on the board

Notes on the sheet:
Manual CLK
Normal CLK
Reset

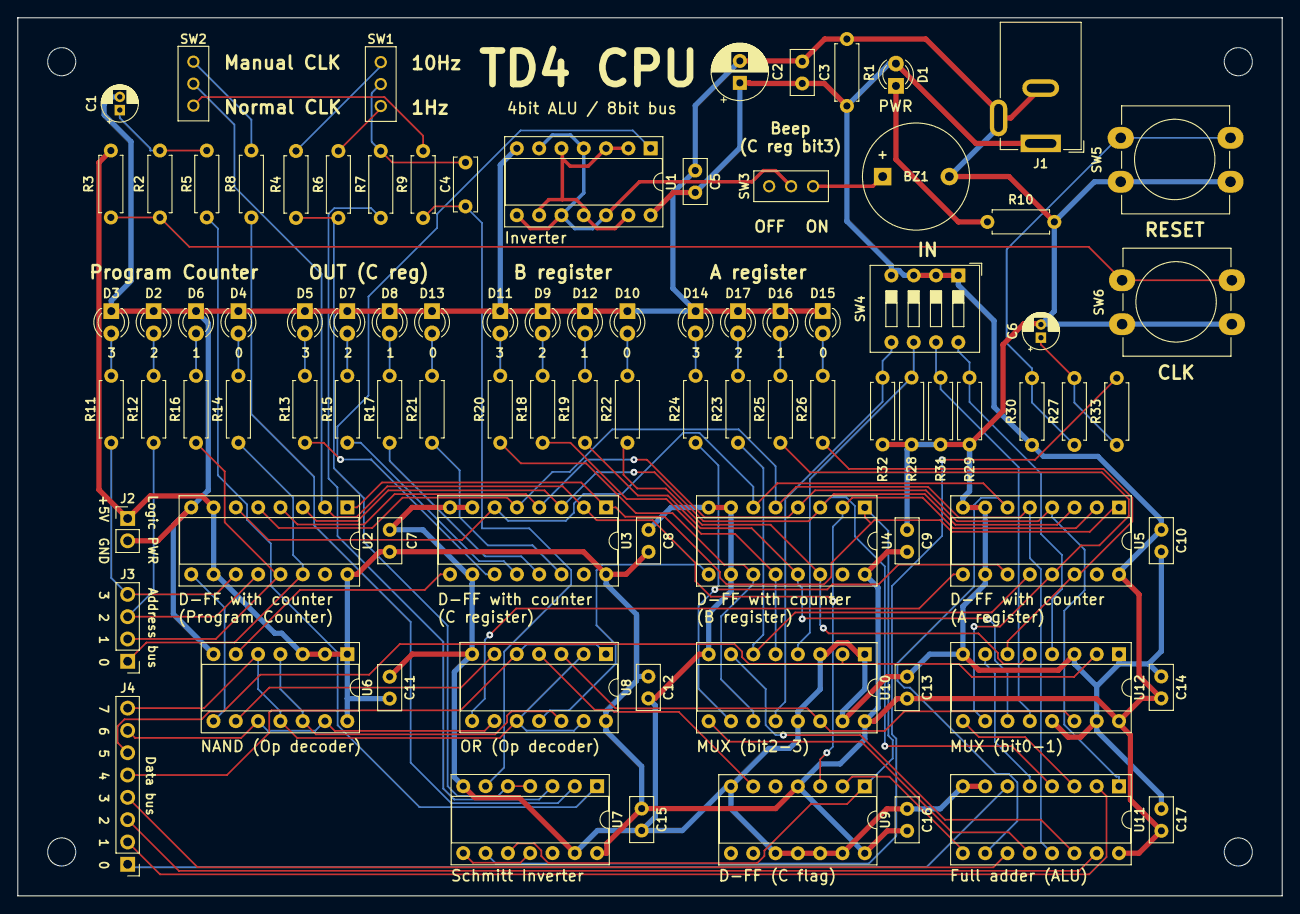
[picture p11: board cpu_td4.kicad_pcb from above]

Board: 2 copper layers, 144.0 x 100.0 mm, 90 parts (0 on the bottom side), 85 nets.

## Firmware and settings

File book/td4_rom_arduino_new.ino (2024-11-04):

// rom data define
uint8_t rom[] = {0xb3, 0xb6, 0xbc, 0xb8, 0xb8, 0xbc, 0xb6, 0xb3, 0xb1, 0xf0, 0x00, 0x00, 0x00, 0x00, 0x00, 0x00};

void writeDataBus(uint8_t data)
{
    digitalWrite(D0, data & 0b00000001);
    digitalWrite(D1, data & 0b00000010);
    digitalWrite(D2, data & 0b00000100);
    digitalWrite(D3, data & 0b00001000);
    digitalWrite(D4, data & 0b00010000);
    digitalWrite(D5, data & 0b00100000);
    digitalWrite(D6, data & 0b01000000);
    digitalWrite(D7, data & 0b10000000);
}

void setup()
{
    // pin mode define
    pinMode(D8, INPUT);
    pinMode(D9, INPUT);
    pinMode(D10, INPUT);
    pinMode(D11, INPUT);

    pinMode(D0, OUTPUT);
    pinMode(D1, OUTPUT);
    pinMode(D2, OUTPUT);
    pinMode(D3, OUTPUT);
    pinMode(D4, OUTPUT);
    pinMode(D5, OUTPUT);
    pinMode(D6, OUTPUT);
    pinMode(D7, OUTPUT);

    writeDataBus(0x00);
}

void loop()
{
    uint8_t address = (bool)digitalRead(D8) | ((bool)digitalRead(D9) << 1) | ((bool)digitalRead(D10) << 2) | ((bool)digitalRead(D11) << 3);

    writeDataBus(rom[address]);
}

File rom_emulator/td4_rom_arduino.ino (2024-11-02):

// rom data define
bool romData[16][8] = {
    {1, 0, 1, 1, 0, 0, 1, 1}, // address 0
    {1, 0, 1, 1, 0, 1, 1, 0}, // address 1
    {1, 0, 1, 1, 1, 1, 0, 0}, // address 2
    {1, 0, 1, 1, 1, 0, 0, 0}, // address 3

    {1, 0, 1, 1, 1, 0, 0, 0}, // address 4
    {1, 0, 1, 1, 1, 1, 0, 0}, // address 5
    {1, 0, 1, 1, 0, 1, 1, 0}, // address 6
    {1, 0, 1, 1, 0, 0, 1, 1}, // address 7

    {1, 0, 1, 1, 0, 0, 0, 1}, // address 8
    {1, 1, 1, 1, 0, 0, 0, 0}, // address 9
    {0, 0, 0, 0, 0, 0, 0, 0}, // address 10
    {0, 0, 0, 0, 0, 0, 0, 0}, // address 11

    {0, 0, 0, 0, 0, 0, 0, 0}, // address 12
    {0, 0, 0, 0, 0, 0, 0, 0}, // address 13
    {0, 0, 0, 0, 0, 0, 0, 0}, // address 14
    {0, 0, 0, 0, 0, 0, 0, 0}, // address 15
};

void writeDataBus(bool data[])
{
    digitalWrite(D0, data[7]);
    digitalWrite(D1, data[6]);
    digitalWrite(D2, data[5]);
    digitalWrite(D3, data[4]);
    digitalWrite(D4, data[3]);
    digitalWrite(D5, data[2]);
    digitalWrite(D6, data[1]);
    digitalWrite(D7, data[0]);
}

void setup()
{
    // pin mode define
    pinMode(D8, INPUT);
    pinMode(D9, INPUT);
    pinMode(D10, INPUT);
    pinMode(D11, INPUT);

    pinMode(D0, OUTPUT);
    pinMode(D1, OUTPUT);
    pinMode(D2, OUTPUT);
    pinMode(D3, OUTPUT);
    pinMode(D4, OUTPUT);
    pinMode(D5, OUTPUT);
    pinMode(D6, OUTPUT);
    pinMode(D7, OUTPUT);

    bool allLow[] = {LOW, LOW, LOW, LOW, LOW, LOW, LOW, LOW};
    writeDataBus(allLow);
}

void loop()
{
    uint8_t address = (bool)digitalRead(D8) | ((bool)digitalRead(D9) << 1) | ((bool)digitalRead(D10) << 2) | ((bool)digitalRead(D11) << 3);

    writeDataBus(romData[address]);
}

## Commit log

2024-11-04 [add] 8bit整数値をROMのデータとして利用できるように変更
2024-11-04 [add] 本の説明書を追加
2024-11-04 [add] PDFのBOMを追加
2024-11-04 ページ数を１削減
2024-11-06 [fix] タイトルの変更とISBNの修正
2024-11-07 [update] 偶数セルに色を付けるように変更
